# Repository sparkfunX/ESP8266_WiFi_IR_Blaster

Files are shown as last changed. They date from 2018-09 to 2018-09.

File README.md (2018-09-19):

SparkX ESP8266 WiFi IR Blaster
========================================

SparkX ESP8266 WiFi IR Blaster (https://www.sparkfun.com/products/15000)

[*SparkX  ESP8266 WiFi IR Blaster (SPX-15000)*](https://www.sparkfun.com/products/15000)

The WiFi IR Blaster is designed to connect all of your old, legacy IR-controlled devices to a WiFi network -- exposing them to a new method of control. Want to control your TV via a web-browser? Want to ask Alexa to mute your stereo? Want to schedule triggers to your IR-controlled LED strip? These are all applications that the WiFi IR Blaster is perfect for.

The WiFi IR Blaster combines an ESP8266 -- a powerful WiFi/microcontroller SoC -- with an IR emitter and receiver. With built-in WiFi support, the ESP8266 can be programmed to provide an interface between HTTP, MQTT, TCP, and UDP services and infrared-controlled devices.

This product includes the WiFi IR Blaster, a [Lite-ON LTE-302](https://www.sparkfun.com/datasheets/Components/LTE-302.pdf) infrared emitter, and a [TSOP38238 IR receiver](https://www.sparkfun.com/products/10266). The IR emitter and detector are not populated on the board -- allowing you to assemble them in any orientation your project requires.

For help getting started, check out our [WiFi IR Blaster Hookup Guide](https://learn.sparkfun.com/tutorials/wifi-ir-blaster-hookup-guide), which explains how to assemble the board, program it, and use the [IRremoteESP8266](https://github.com/markszabo/IRremoteESP8266) Arduino library.

SparkFun labored with love to create this code. Feel like supporting open source hardware? 
Buy a [breakout board](https://www.sparkfun.com/products/15000) from SparkFun!

Repository Contents
-------------------

* **/Documents** - Datasheets
* **/Firmware** - Example code and esp32-Arduino board files

License Information
-------------------

This product is _**open source**_! 

If you have any questions or concerns on licensing, please contact techsupport@sparkfun.com.

Please use, reuse, and modify these files as you see fit. Please maintain attribution to SparkFun Electronics and release any derivative under the same license.

Distributed as-is; no warranty is given.

- Your friends at SparkFun.

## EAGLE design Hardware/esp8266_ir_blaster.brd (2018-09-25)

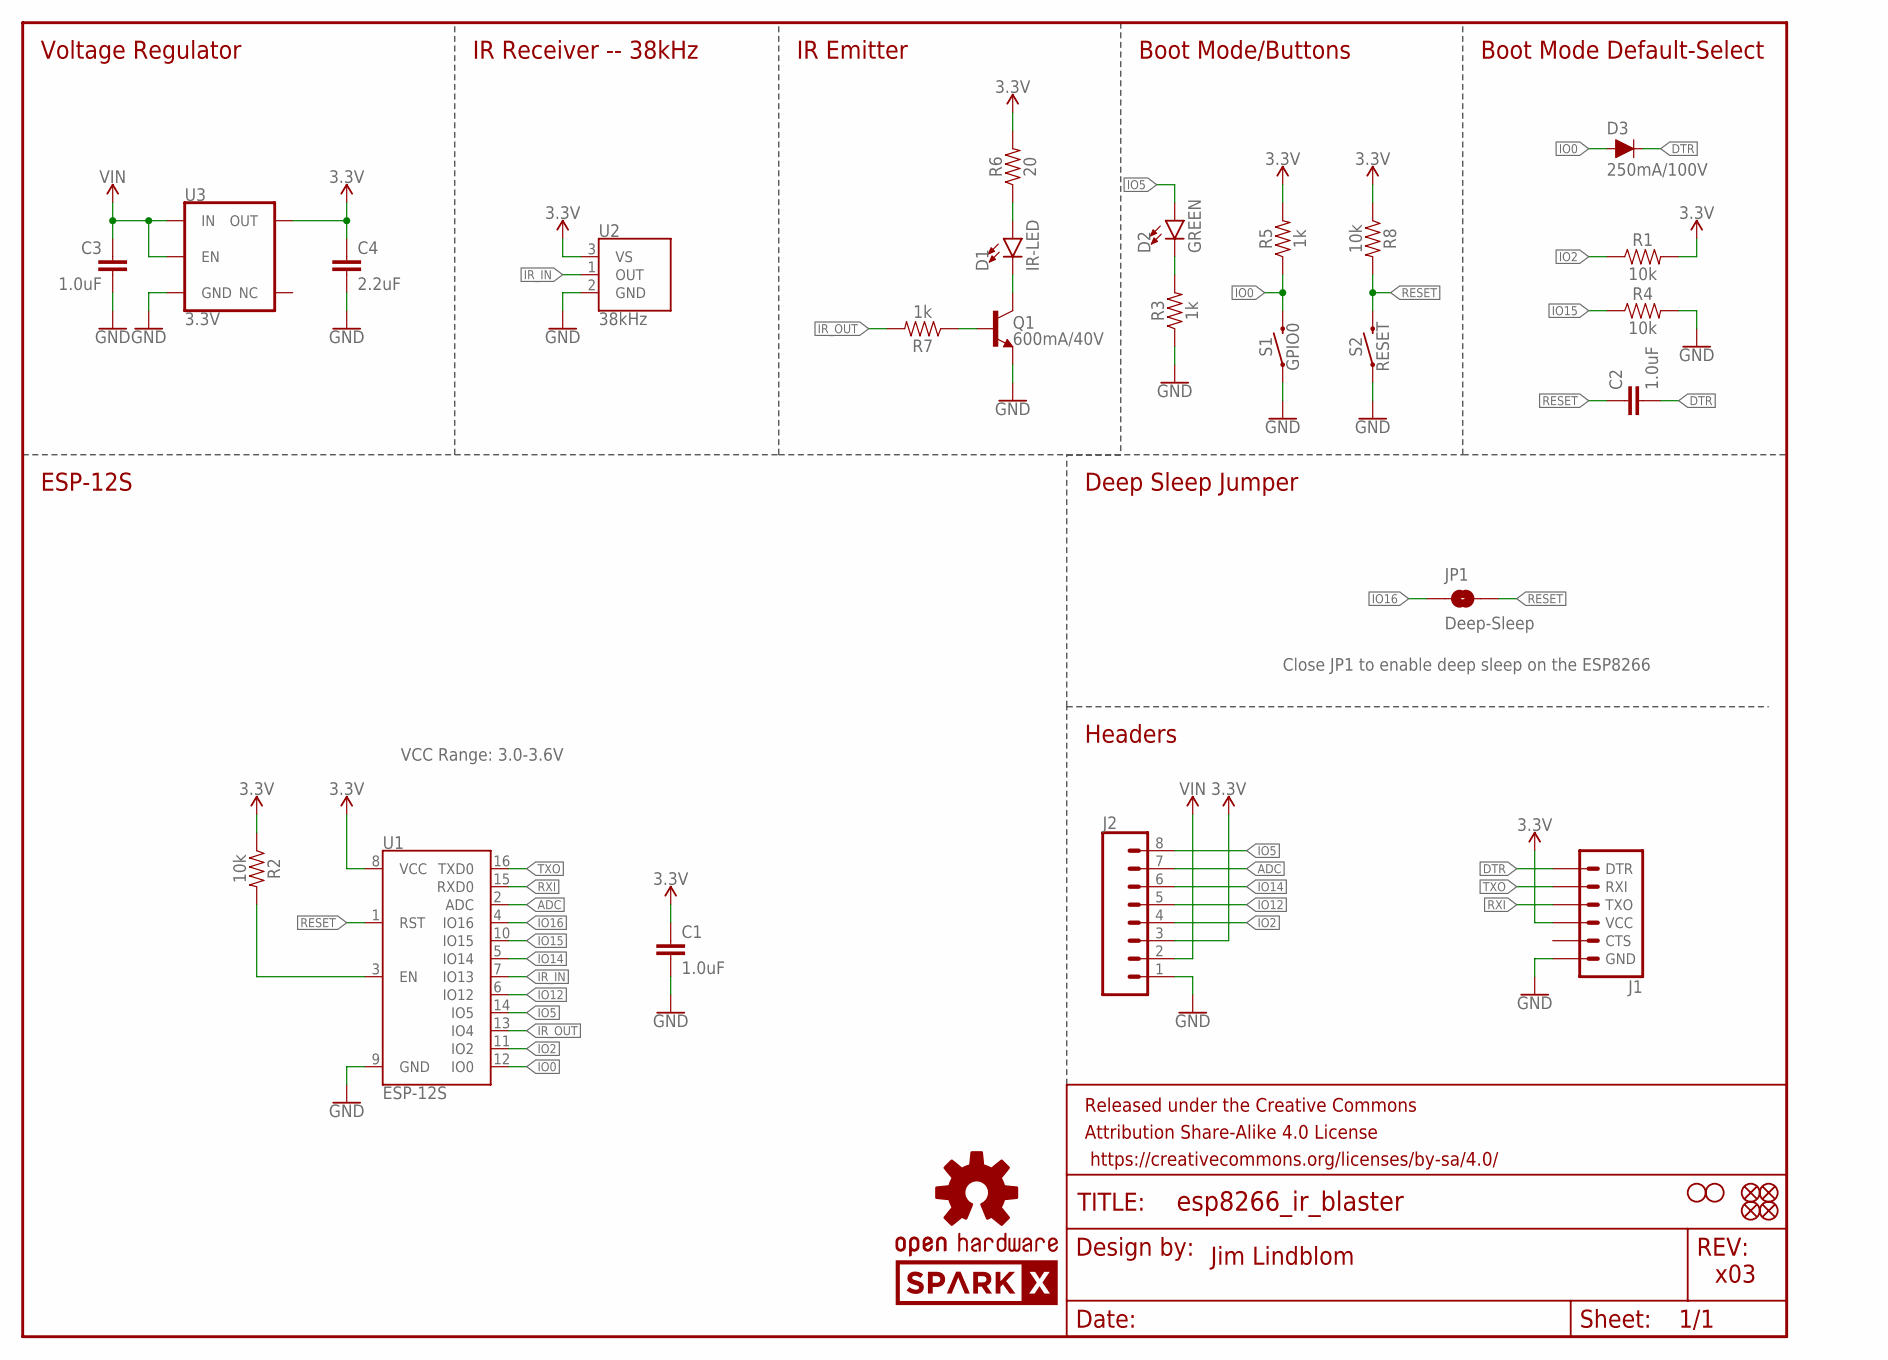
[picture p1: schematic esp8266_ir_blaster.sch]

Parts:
C1, C2, C3: 1.0uF; 0603
C4: 2.2uF; 0603
D1: IR-LED; LTE-302
D2: GREEN; LED-0603
D3: 250mA/100V; SOD-323
FD1, FD2, FD3, FD4: FIDUCIALUFIDUCIAL; FIDUCIAL-MICRO
FRAME1: FRAME-LETTER; CREATIVE_COMMONS
H1, H2: STAND-OFF
J1: 6_PIN_SERIAL_TARGETNO_SILK; 1X06_NO_SILK
J2: CONN_08NO_SILK_FEMALE_PTH; 1X08_NO_SILK
JP1: Deep-Sleep; SMT-JUMPER_2_NO_NO-SILK
LOGO1: OSHW-LOGOS; OSHW-LOGO-S
LOGO2: SPARKX-LOGO5; SPARKX-LARGE
Q1: 600mA/40V; SOT23-3
R1, R2, R4, R8: 10k; 0603
R3, R5, R7: 1k; 0603
R6: 20; 0603
S1: GPIO0; TACTILE_SWITCH_SMD_4.6X2.8MM
S2: RESET; TACTILE_SWITCH_SMD_4.6X2.8MM
U1: ESP-12S
U2: 38kHz; TSOP382
U3: 3.3V; SOT23-5

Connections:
3.3V: C1.1, C4.1, J1.4 (VCC), J2.3, R1.2, R2.1, R5.2, R6.2, R8.1, U1.8 (VCC), U2.3 (VS), U3.5 (OUT)
ADC: J2.7, U1.2 (ADC)
CHIP_EN: R2.2, U1.3 (EN)
DTR: C2.2, D3.C, J1.1 (DTR)
GND: C1.2, C3.2, C4.2, J1.6 (GND), J2.1, Q1.2 (E), R3.1, R4.2, S1.1, S1.2 (1), S2.1, S2.2 (1), U1.9 (GND), U2.2 (GND), U3.2 (GND)
IO0: D3.A, R5.1, S1.3 (2), S1.4 (2), U1.12 (IO0)
IO2: J2.4, R1.1, U1.11 (IO2)
IO5: D2.A, J2.8, U1.14 (IO5)
IO12: J2.5, U1.6 (IO12)
IO14: J2.6, U1.5 (IO14)
IO15: R4.1, U1.10 (IO15)
IO16: JP1.1, U1.4 (IO16)
IR_IN: U1.7 (IO13), U2.1 (OUT)
IR_OUT: R7.2, U1.13 (IO4)
unnamed: D2.C, R3.2
unnamed: D1.C, Q1.3 (C)
unnamed: D1.A, R6.1
unnamed: Q1.1 (B), R7.1
RESET: C2.1, JP1.2, R8.2, S2.3 (2), S2.4 (2), U1.1 (RST)
RXI: J1.3 (TXO), U1.15 (RXD0)
TXO: J1.2 (RXI), U1.16 (TXD0)
VIN: C3.1, J2.2, U3.1 (IN), U3.3 (EN)

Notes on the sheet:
Jim Lindblom
x03
IR Receiver -- 38kHz
IR Emitter
Boot Mode/Buttons
Boot Mode Default-Select
Deep Sleep Jumper
Headers
ESP-12S
Close JP1 to enable deep sleep on the ESP8266
VCC Range: 3.0-3.6V
Voltage Regulator

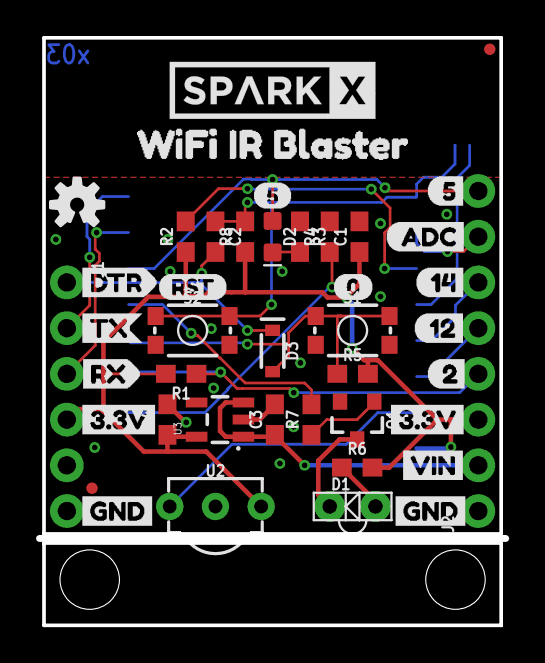
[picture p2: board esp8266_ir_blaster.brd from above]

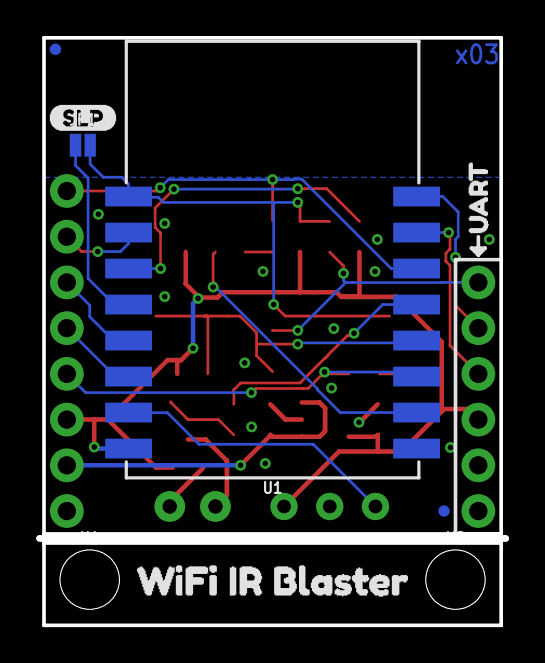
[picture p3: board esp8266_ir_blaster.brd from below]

Board: 2 copper layers, 25.9 x 32.6 mm, 53 parts (9 on the bottom side), 22 nets.

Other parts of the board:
U$1: 512
U$2, U$21: 3#3V4
U$3: SLP14
U$4, U$13: WIFI_IR_BLASTER11
U$5: UART0
U$6: DTR1
U$8: 511
U$9: ADC10
U$10: 129
U$11: 148
U$12: 27
U$14: 013
U$15: RST14
U$19: TX2
U$20: RX3
U$22, U$24: GND5
U$23: VIN6

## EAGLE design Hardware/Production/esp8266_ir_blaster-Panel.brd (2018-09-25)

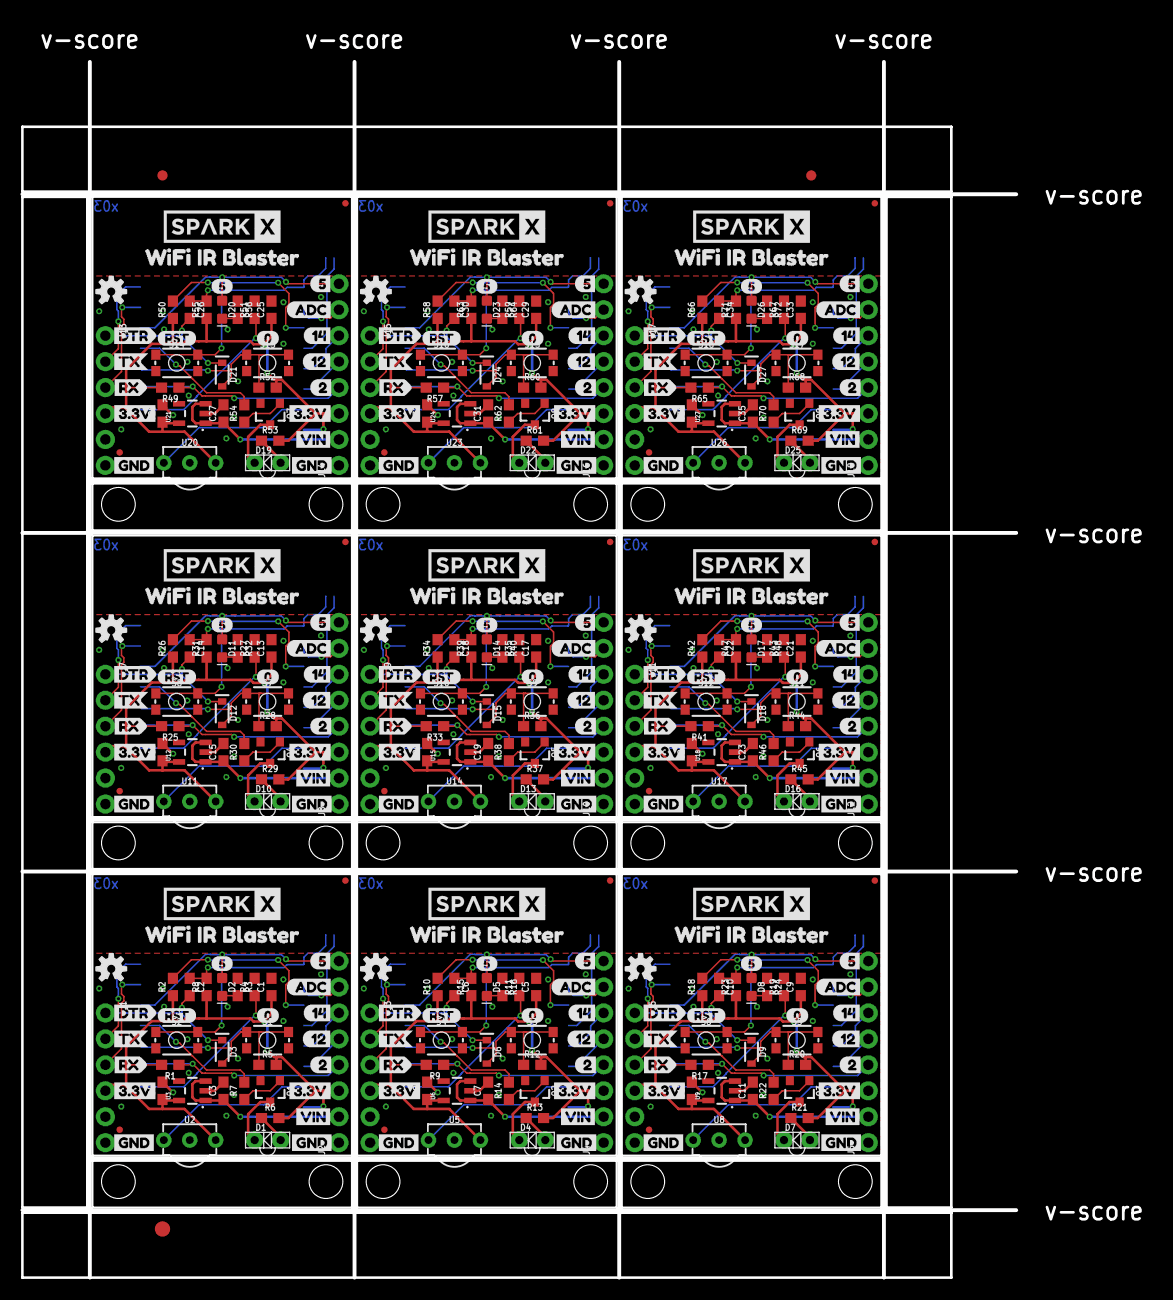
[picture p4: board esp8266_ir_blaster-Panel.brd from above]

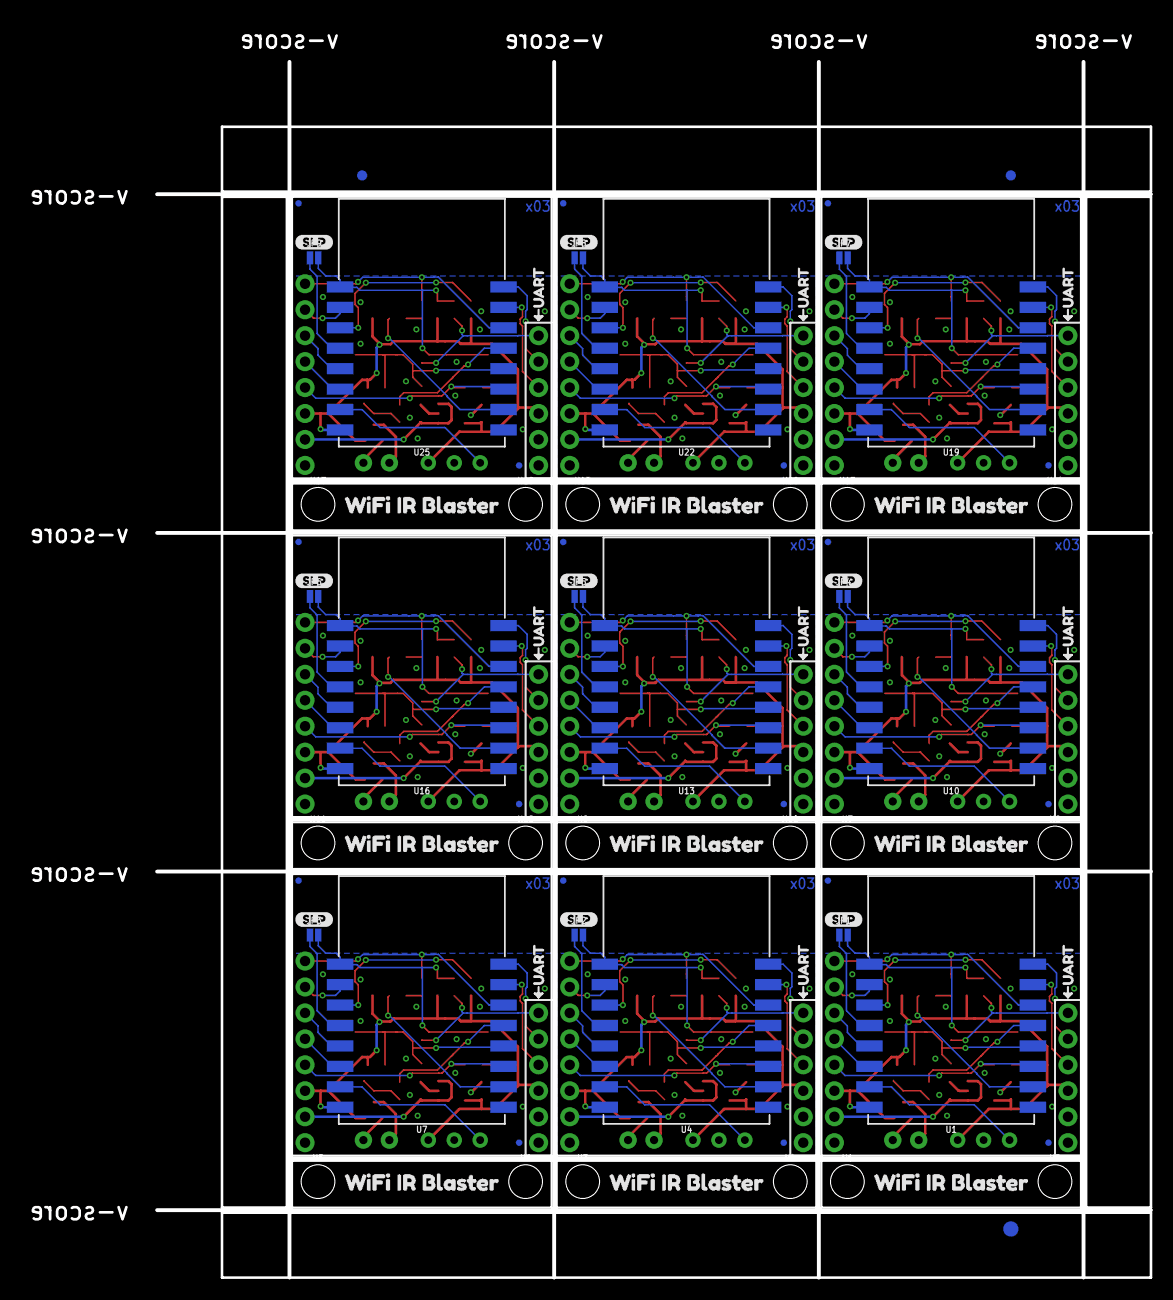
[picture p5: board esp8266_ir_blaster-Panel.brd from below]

Board: 2 copper layers, 97.3 x 119.0 mm, 474 parts (84 on the bottom side), 198 nets.

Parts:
C1, C2, C3, C5, C6, C7, C9, C10, C11, C13, C14, C15, C17, C18, C19, C21, C22, C23, C25, C26, C27, C29, C30, C31, C33, C34, C35: 1.0uF; 0603
C4, C8, C12, C16, C20, C24, C28, C32, C36: 2.2uF; 0603
D1, D4, D7, D10, D13, D16, D19, D22, D25: IR-LED; LTE-302
D2, D5, D8, D11, D14, D17, D20, D23, D26: GREEN; LED-0603
D3, D6, D9, D12, D15, D18, D21, D24, D27: 250mA/100V; SOD-323
E$1, E$2, E$3, E$4: FIDUCIAL-1X2
E$5, E$6: FIDUCIAL-1.5X3
FD1, FD2, FD3, FD4, FD5, FD6, FD7, FD8, FD9, FD10, FD11, FD12, FD13, FD14, FD15, FD16, FD17, FD18, FD19, FD20, FD21, FD22, FD23, FD24, FD25, FD26, FD27, FD28, FD29, FD30, FD31, FD32, FD33, FD34, FD35, FD36: FIDUCIALUFIDUCIAL; FIDUCIAL-MICRO
H1, H2, H3, H4, H5, H6, H7, H8, H9, H10, H11, H12, H13, H14, H15, H16, H17, H18: STAND-OFF
J1, J3, J5, J7, J9, J11, J13, J15, J17: 1X06_NO_SILK
J2, J4, J6, J8, J10, J12, J14, J16, J18: 1X08_NO_SILK
JP1, JP2, JP3, JP4, JP5, JP6, JP7, JP8, JP9: Deep-Sleep; SMT-JUMPER_2_NO_NO-SILK
LOGO1, LOGO4, LOGO6, LOGO8, LOGO10, LOGO12, LOGO14, LOGO16, LOGO18: OSHW-LOGOS; OSHW-LOGO-S
LOGO2, LOGO3, LOGO5, LOGO7, LOGO9, LOGO11, LOGO13, LOGO15, LOGO17: SPARKX-LOGO5; SPARKX-LARGE
Q1, Q2, Q3, Q4, Q5, Q6, Q7, Q8, Q9: 600mA/40V; SOT23-3
R1, R2, R4, R8, R9, R10, R11, R15, R17, R18, R19, R23, R25, R26, R27, R31, R33, R34, R35, R39, R41, R42, R43, R47, R49, R50, R51, R55, R57, R58, R59, R63, R65, R66, R67, R71: 10k; 0603
R3, R5, R7, R12, R14, R16, R20, R22, R24, R28, R30, R32, R36, R38, R40, R44, R46, R48, R52, R54, R56, R60, R62, R64, R68, R70, R72: 1k; 0603
R6, R13, R21, R29, R37, R45, R53, R61, R69: 20; 0603
S1, S3, S5, S7, S9, S11, S13, S15, S17: GPIO0; TACTILE_SWITCH_SMD_4.6X2.8MM
S2, S4, S6, S8, S10, S12, S14, S16, S18: RESET; TACTILE_SWITCH_SMD_4.6X2.8MM
U1, U4, U7, U10, U13, U16, U19, U22, U25: ESP-12S
U2, U5, U8, U11, U14, U17, U20, U23, U26: 38kHz; TSOP382
U3, U6, U9, U12, U15, U18, U21, U24, U27: 3.3V; SOT23-5
U$1, U$36, U$56, U$76, U$96, U$116, U$136, U$156, U$176: 512
U$2, U$21, U$27, U$37, U$47, U$57, U$67, U$77, U$87, U$97, U$107, U$117, U$127, U$137, U$147, U$157, U$167, U$177: 3#3V4
U$3, U$38, U$58, U$78, U$98, U$118, U$138, U$158, U$178: SLP14
U$4, U$7, U$13, U$39, U$41, U$59, U$61, U$79, U$81, U$99, U$101, U$119, U$121, U$139, U$141, U$159, U$161, U$179: WIFI_IR_BLASTER11
U$5, U$40, U$60, U$80, U$100, U$120, U$140, U$160, U$180: UART0
U$6, U$18, U$44, U$64, U$84, U$104, U$124, U$144, U$164: DTR1
U$8, U$29, U$49, U$69, U$89, U$109, U$129, U$149, U$169: 511
U$9, U$30, U$50, U$70, U$90, U$110, U$130, U$150, U$170: ADC10
U$10, U$31, U$51, U$71, U$91, U$111, U$131, U$151, U$171: 129
U$11, U$32, U$52, U$72, U$92, U$112, U$132, U$152, U$172: 148
U$12, U$33, U$53, U$73, U$93, U$113, U$133, U$153, U$173: 27
U$14, U$16, U$42, U$62, U$82, U$102, U$122, U$142, U$162: 013
U$15, U$17, U$43, U$63, U$83, U$103, U$123, U$143, U$163: RST14
U$19, U$25, U$45, U$65, U$85, U$105, U$125, U$145, U$165: TX2
U$20, U$26, U$46, U$66, U$86, U$106, U$126, U$146, U$166: RX3
U$22, U$24, U$28, U$35, U$48, U$55, U$68, U$75, U$88, U$95, U$108, U$115, U$128, U$135, U$148, U$155, U$168, U$175: GND5
U$23, U$34, U$54, U$74, U$94, U$114, U$134, U$154, U$174: VIN6

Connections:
3.3V: C1.1, C4.1, J1.4, J2.3, R1.2, R2.1, R5.2, R6.2, R8.1, U1.8, U2.3, U3.5
3.3V1: C5.1, C8.1, J3.4, J4.3, R9.2, R10.1, R12.2, R13.2, R15.1, U4.8, U5.3, U6.5
3.3V2: C9.1, C12.1, J5.4, J6.3, R17.2, R18.1, R20.2, R21.2, R23.1, U7.8, U8.3, U9.5
3.3V3: C13.1, C16.1, J7.4, J8.3, R25.2, R26.1, R28.2, R29.2, R31.1, U10.8, U11.3, U12.5
3.3V4: C17.1, C20.1, J9.4, J10.3, R33.2, R34.1, R36.2, R37.2, R39.1, U13.8, U14.3, U15.5
3.3V5: C21.1, C24.1, J11.4, J12.3, R41.2, R42.1, R44.2, R45.2, R47.1, U16.8, U17.3, U18.5
3.3V6: C25.1, C28.1, J13.4, J14.3, R49.2, R50.1, R52.2, R53.2, R55.1, U19.8, U20.3, U21.5
3.3V7: C29.1, C32.1, J15.4, J16.3, R57.2, R58.1, R60.2, R61.2, R63.1, U22.8, U23.3, U24.5
3.3V8: C33.1, C36.1, J17.4, J18.3, R65.2, R66.1, R68.2, R69.2, R71.1, U25.8, U26.3, U27.5
ADC: J2.7, U1.2
ADC1: J4.7, U4.2
ADC2: J6.7, U7.2
ADC3: J8.7, U10.2
ADC4: J10.7, U13.2
ADC5: J12.7, U16.2
ADC6: J14.7, U19.2
ADC7: J16.7, U22.2
ADC8: J18.7, U25.2
CHIP_EN: R2.2, U1.3
CHIP_EN1: R10.2, U4.3
CHIP_EN2: R18.2, U7.3
CHIP_EN3: R26.2, U10.3
CHIP_EN4: R34.2, U13.3
CHIP_EN5: R42.2, U16.3
CHIP_EN6: R50.2, U19.3
CHIP_EN7: R58.2, U22.3
CHIP_EN8: R66.2, U25.3
DTR: C2.2, D3.C, J1.1
DTR1: C6.2, D6.C, J3.1
DTR2: C10.2, D9.C, J5.1
DTR3: C14.2, D12.C, J7.1
DTR4: C18.2, D15.C, J9.1
DTR5: C22.2, D18.C, J11.1
DTR6: C26.2, D21.C, J13.1
DTR7: C30.2, D24.C, J15.1
DTR8: C34.2, D27.C, J17.1
GND: C1.2, C3.2, C4.2, J1.6, J2.1, Q1.2, R3.1, R4.2, S1.1, S1.2, S2.1, S2.2, U1.9, U2.2, U3.2
GND1: C5.2, C7.2, C8.2, J3.6, J4.1, Q2.2, R11.2, R16.1, S3.1, S3.2, S4.1, S4.2, U4.9, U5.2, U6.2
GND2: C9.2, C11.2, C12.2, J5.6, J6.1, Q3.2, R19.2, R24.1, S5.1, S5.2, S6.1, S6.2, U7.9, U8.2, U9.2
GND3: C13.2, C15.2, C16.2, J7.6, J8.1, Q4.2, R27.2, R32.1, S7.1, S7.2, S8.1, S8.2, U10.9, U11.2, U12.2
GND4: C17.2, C19.2, C20.2, J9.6, J10.1, Q5.2, R35.2, R40.1, S9.1, S9.2, S10.1, S10.2, U13.9, U14.2, U15.2
GND5: C21.2, C23.2, C24.2, J11.6, J12.1, Q6.2, R43.2, R48.1, S11.1, S11.2, S12.1, S12.2, U16.9, U17.2, U18.2
GND6: C25.2, C27.2, C28.2, J13.6, J14.1, Q7.2, R51.2, R56.1, S13.1, S13.2, S14.1, S14.2, U19.9, U20.2, U21.2
GND7: C29.2, C31.2, C32.2, J15.6, J16.1, Q8.2, R59.2, R64.1, S15.1, S15.2, S16.1, S16.2, U22.9, U23.2, U24.2
GND8: C33.2, C35.2, C36.2, J17.6, J18.1, Q9.2, R67.2, R72.1, S17.1, S17.2, S18.1, S18.2, U25.9, U26.2, U27.2
IO0: D3.A, R5.1, S1.3, S1.4, U1.12
IO1: R11.1, U4.10
IO2: J2.4, R1.1, U1.11
IO3: J4.4, R9.1, U4.11
IO4: D6.A, R12.1, S3.3, S3.4, U4.12
IO5: D2.A, J2.8, U1.14
IO6: J4.6, U4.5
IO7: JP2.1, U4.4
IO8: J4.5, U4.6
IO9: D5.A, J4.8, U4.14
IO10: R19.1, U7.10
IO11: J6.4, R17.1, U7.11
IO12: J2.5, U1.6
IO13: D9.A, R20.1, S5.3, S5.4, U7.12
IO14: J2.6, U1.5
IO15: R4.1, U1.10
IO16: JP1.1, U1.4
IO17: J6.6, U7.5
IO18: JP3.1, U7.4
IO19: J6.5, U7.6
IO20: D8.A, J6.8, U7.14
IO21: R27.1, U10.10
IO22: J8.4, R25.1, U10.11
IO23: D12.A, R28.1, S7.3, S7.4, U10.12
IO24: J8.6, U10.5
IO25: JP4.1, U10.4
IO26: J8.5, U10.6
IO27: D11.A, J8.8, U10.14
IO28: R35.1, U13.10
IO29: J10.4, R33.1, U13.11
IO30: D15.A, R36.1, S9.3, S9.4, U13.12
IO31: J10.6, U13.5
IO32: JP5.1, U13.4
IO33: J10.5, U13.6
IO34: D14.A, J10.8, U13.14
IO35: R43.1, U16.10
IO36: J12.4, R41.1, U16.11
IO37: D18.A, R44.1, S11.3, S11.4, U16.12
IO38: J12.6, U16.5
IO39: JP6.1, U16.4
IO40: J12.5, U16.6
IO41: D17.A, J12.8, U16.14
IO42: R51.1, U19.10
IO43: J14.4, R49.1, U19.11
IO44: D21.A, R52.1, S13.3, S13.4, U19.12
IO45: J14.6, U19.5
IO46: JP7.1, U19.4
IO47: J14.5, U19.6
IO48: D20.A, J14.8, U19.14
IO49: R59.1, U22.10
IO50: J16.4, R57.1, U22.11
IO51: D24.A, R60.1, S15.3, S15.4, U22.12
IO52: J16.6, U22.5
IO53: JP8.1, U22.4
IO54: J16.5, U22.6
IO55: D23.A, J16.8, U22.14
IO56: R67.1, U25.10
IO57: J18.4, R65.1, U25.11
IO58: D27.A, R68.1, S17.3, S17.4, U25.12
IO59: J18.6, U25.5
IO60: JP9.1, U25.4
IO61: J18.5, U25.6
IO62: D26.A, J18.8, U25.14
IR_IN: U1.7, U2.1
IR_IN1: U4.7, U5.1
IR_IN2: U7.7, U8.1
IR_IN3: U10.7, U11.1
IR_IN4: U13.7, U14.1
IR_IN5: U16.7, U17.1
IR_IN6: U19.7, U20.1
IR_IN7: U22.7, U23.1
IR_IN8: U25.7, U26.1
IR_OUT: R7.2, U1.13
IR_OUT1: R14.2, U4.13
IR_OUT2: R22.2, U7.13
IR_OUT3: R30.2, U10.13
IR_OUT4: R38.2, U13.13
IR_OUT5: R46.2, U16.13
IR_OUT6: R54.2, U19.13
IR_OUT7: R62.2, U22.13
IR_OUT8: R70.2, U25.13
unnamed: D2.C, R3.2
unnamed: D4.C, Q2.3
unnamed: D4.A, R13.1
unnamed: Q2.1, R14.1
unnamed: D1.C, Q1.3
unnamed: D1.A, R6.1
unnamed: Q1.1, R7.1
unnamed: D5.C, R16.2
unnamed: D7.C, Q3.3
unnamed: D7.A, R21.1
unnamed: Q3.1, R22.1
unnamed: D8.C, R24.2
unnamed: D10.C, Q4.3
unnamed: D10.A, R29.1
unnamed: Q4.1, R30.1
unnamed: D11.C, R32.2
unnamed: D13.C, Q5.3
unnamed: D13.A, R37.1
unnamed: Q5.1, R38.1
unnamed: D14.C, R40.2
unnamed: D16.C, Q6.3
unnamed: D16.A, R45.1
unnamed: Q6.1, R46.1
unnamed: D17.C, R48.2
unnamed: D19.C, Q7.3
unnamed: D19.A, R53.1
unnamed: Q7.1, R54.1
unnamed: D20.C, R56.2
unnamed: D22.C, Q8.3
unnamed: D22.A, R61.1
unnamed: Q8.1, R62.1
unnamed: D23.C, R64.2
unnamed: D25.C, Q9.3
unnamed: D25.A, R69.1
unnamed: Q9.1, R70.1
unnamed: D26.C, R72.2
RESET: C2.1, JP1.2, R8.2, S2.3, S2.4, U1.1
RESET1: C6.1, JP2.2, R15.2, S4.3, S4.4, U4.1
RESET2: C10.1, JP3.2, R23.2, S6.3, S6.4, U7.1
RESET3: C14.1, JP4.2, R31.2, S8.3, S8.4, U10.1
RESET4: C18.1, JP5.2, R39.2, S10.3, S10.4, U13.1
RESET5: C22.1, JP6.2, R47.2, S12.3, S12.4, U16.1
RESET6: C26.1, JP7.2, R55.2, S14.3, S14.4, U19.1
RESET7: C30.1, JP8.2, R63.2, S16.3, S16.4, U22.1
RESET8: C34.1, JP9.2, R71.2, S18.3, S18.4, U25.1
RXI: J1.3, U1.15
RXI1: J3.3, U4.15
RXI2: J5.3, U7.15
RXI3: J7.3, U10.15
RXI4: J9.3, U13.15
RXI5: J11.3, U16.15
RXI6: J13.3, U19.15
RXI7: J15.3, U22.15
RXI8: J17.3, U25.15
TXO: J1.2, U1.16
TXO1: J3.2, U4.16
TXO2: J5.2, U7.16
TXO3: J7.2, U10.16
TXO4: J9.2, U13.16
TXO5: J11.2, U16.16
TXO6: J13.2, U19.16
TXO7: J15.2, U22.16
TXO8: J17.2, U25.16
VIN: C3.1, J2.2, U3.1, U3.3
VIN1: C7.1, J4.2, U6.1, U6.3
VIN2: C11.1, J6.2, U9.1, U9.3
VIN3: C15.1, J8.2, U12.1, U12.3
VIN4: C19.1, J10.2, U15.1, U15.3
VIN5: C23.1, J12.2, U18.1, U18.3
VIN6: C27.1, J14.2, U21.1, U21.3
VIN7: C31.1, J16.2, U24.1, U24.3
VIN8: C35.1, J18.2, U27.1, U27.3

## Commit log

2018-06-19 initial commit of hardware
    [esp8266_ir_blaster.brd, esp8266_ir_blaster.sch]
2018-06-19 x01 panel
    [esp8266_ir_blaster-Panel.GBL, esp8266_ir_blaster-Panel.GBO, esp8266_ir_blaster-Panel.GBP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]
2018-07-18 Revising LED color. Adding production panel.
    [esp8266_ir_blaster-Panel.GBL, esp8266_ir_blaster-Panel.GBO, esp8266_ir_blaster-Panel.GBP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]
2018-08-07 x02 hardware commit
    [esp8266_ir_blaster-Panel.GBL, esp8266_ir_blaster-Panel.GBO, esp8266_ir_blaster-Panel.GBP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]
2018-09-18 Adding x02 schematic.
2018-09-25 Increasing drill size for IR receiver holes.
    [esp8266_ir_blaster-Panel.brd, esp8266_ir_blaster.brd, esp8266_ir_blaster.sch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]

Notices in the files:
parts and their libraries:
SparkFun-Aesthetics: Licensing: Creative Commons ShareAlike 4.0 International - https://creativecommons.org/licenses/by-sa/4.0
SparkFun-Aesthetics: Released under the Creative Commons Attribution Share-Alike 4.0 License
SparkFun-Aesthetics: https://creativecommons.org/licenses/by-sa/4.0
